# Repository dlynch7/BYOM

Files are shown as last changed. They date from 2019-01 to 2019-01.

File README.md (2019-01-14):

# [B]uild [Y]our [O]wn [M]otor
Build and control a brushless DC (BLDC) motor.

Introductory project for Robot Design Studio (ME 495/EECS 495) 2019 at Northwestern University.

The project name is a bit of a misnomer: you won't build a motor from scratch, however you will be able to select from a number of motor winding options, allowing you to make design decisions about the motor's speed-torque curve.

## Parts list
- [Turnigy TrackStar 21.5T sensored BLDC motor](https://hobbyking.com/en_us/turnigy-trackstar-21-5t-sensored-brushless-motor-1855kv-roar-approved.html)
- [Texas Instruments EK-TM4C123GXL LaunchPad](http://www.ti.com/tool/EK-TM4C123GXL) (evaluation kit for Tiva TM4C123GH6PM microcontroller)
- [Texas Instruments BOOSTXL-DRV8323RS](http://www.ti.com/general/docs/litabsmultiplefilelist.tsp?literatureNumber=slvub01c) (evaluation kit for DRV8323Rx gate driver IC)

## BLDC connector
The BLDC has a 6-pin connector, but because it isn't immediately clear what each pin does, I removed the top half of the can and did some probing with a multimeter.

Inside, the Hall sensors are mounted to a circular PCB that sits above the coils.
The Halls are surface-mount components much like [these ones from TI](http://www.ti.com/product/DRV5055), with GND on one side of the IC and VCC and OUT both on the other side, which probably makes it harder to short across GND and Vcc.

Assuming the Halls inside this motor have the same pinout (and I saw many online with this pinout), I was able to figure out which of the 6 pins are VCC and GND, and in short order I had figured out which of the remaining pins were the outputs for the three Hall sensors.

That still left one mystery pin, which I traced to a small 2-pad surface mount component that I suspect is a temperature sensor.

Thus, looking top-down with phase markings right-side-up, the connector pinout is
`GND HALL_1 HALL_2 HALL_3 TEMP VCC`.

## Pin compatibility check: Tiva and motor driver
The BOOSTXL-DRV8323 motor driver devboard was designed to work TI's MSP430 devboard, and although the BOOSTXL devboard snaps onto the Tiva devboard, I want to make sure the pins are compatibile.

TI's documentation for the BOOSTXL-DRV8323 devboard provides a nice table detailing the pin connections between the BOOSTXL-DRV8323 and the MSP430 devboard and explains each pin's functions.
I am reproducing it below and adding a column for the Tiva devboard pins.

<details><summary> Click to expand pin compatibility table</summary>
<p>

| BOOSTXL-DRV8323 pin | BOOSTXL-DRV8323 function | MSP430 pin, function  | Tiva pin, function |
| --- | --- | --- | --- |
| J3-1 | 3.3 V | 3.3 V | 3.3 V |
| J3-2 | no function | 5 V | 5 V |
| J3-3 | VSENVM | P6.5, ADC - A5 | PB5, AIN 11 |
| J3-4 | GND | GND | GND |
| J3-5 | no function | P3.4, I/O pin | PB0, I/O pin |
| J3-6 | VSENA | P6.0, ADC - 0 | PD0, AIN 7 |
| J3-7 | no function | P3.3, I/O pin | PB1, I/O pin |
| J3-8 | VSENB | P6.1, ADC - 1 | PD1, AIN 6 |
| J3-9 | ENABLE | P1.6, I/O w/ INT | PE4, I/O w/ INT |
| J3-10 | VSENC | P6.2, ADC - 2 | PD2, AIN 5 |
| J3-11 | POT | P6.6, ADC - A6 | PE5, AIN 8 |
| J3-12 | ISENC | P6.3, ADC - 3 | PD3, AIN 4 |
| J3-13 | SCLK | P3.2, SPI CLK | PB4, SSI2 CLK |
| J3-14 | ISENB | P6.4, ADC - 4 | PE1, AIN 2 |
| J3-15 | NFAULT | P2.7, I/O w/ INT | PA5, I/O w/ INT |
| J3-16 | ISENA | P7.0, ADC - 12 | PE2, AIN 1 |
| J3-17 | no function | P4.2, I/O pin | PA6, I/O pin |
| J3-18 | IDRIVE | P3.6, I/O pin | PE3, I/O pin |
| J3-19 | no function | P4.1, I/O pin | PA7, I/O pin |
| J3-20 | VDS | P3.5, I/O pin | PF1, I/O pin |
| J4-1 | INHA | P2.5, TA2.2 | PF2, M1PWM6 |
| J4-2 | GND | GND | GND |
| J4-3 | INLA | P2.4, TA2.1 | PF3, M1PWM7 |
| J4-4 | HALLA | P2.0, SPI ENABLE | PB2, I/O w/ INT |
| J4-5 | INHB | P1.5, TA0.4 | PB3, T3CCP1 |
| J4-6 | HALLB | P2.2, I/O w/ INT | PE0, I/O w/ INT |
| J4-7 | INLB | P1.4, TA0.3 | PC4, M0PWM6 |
| J4-8 | no function | P7.4, I/O pin | PF0, I/O pin |
| J4-9 | INHC | P1.3, TA0.2 | PC5, M0PWM7 |
| J4-10 | no function | RST | RST |
| J4-11 | INLC | P1.2, TA0.1 | PC6 |
| J4-12 | SDI | P3.0, MOSI | PB7, MOSI |
| J4-13 | MODE | P4.3, I/O pin | PC7 |
| J4-14 | SDO | P3.1, MISO | PB6, MISO |
| J4-15 | LED | P4.0, I/O pin | PD6, I/O pin |
| J4-16 | HALLC | P2.6, I/O w/ INT | PA4, I/O w/ INT |
| J4-17 | EVM ID | P3.7, I/O pin | PD7, I/O pin |
| J4-18 | nSCS/GAIN | P2.2, I/O w/ INT | PA3, I/O w/ INT |
| J4-19 | EVM ID | P8.2, I/O pin | PF4, I/O pin |
| J4-20 | CAL | P8.1, I/O pin | PA2, I/O pin |

</p>
</details>

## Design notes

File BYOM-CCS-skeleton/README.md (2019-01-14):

# BYOM-CCS-skeleton
Comments-only template for BYOM project.
Most of the code is stripped out, except for a few basic functions.
You will follow the guidelines in the comments to write your own code.

## Basic guidelines
* `bldc.{c,h}` contains high-level commutation code and should be hardware-agnostic.
* `drv8323rs.{c,h}` contains hardware-specific code and not high-level commutation code.
* `setup.{c,h}` contains functions that initialize other things not essential to BLDC commutation.
* Call all setup functions from the main function inside `main.c`. Don't write out any setup functions inside the main function in `main.c`; define them in the appropriate C file.
* All hardware interrupts need to be registered in the interrupt vector table in `tm4c123gh6pm_startup_ccs.c`. Pay attention to the use of the `extern` keyword in the function prototypes of the Hall sensor interrupt handlers in `drv8323rs.h` (the functions are defined in `bldc.c`).
* If your program hangs during execution and you have debugged your functions, you may need to increase the stack size. CCS has made this hard to find.
    * Right-click on your project in the 'Project Explorer' window, then click on 'Properties', scroll down on the left and expand the options for 'ARM Linker', and then click on 'Basic Options'.
    * This should bring up a dialog with an option to 'Set C system stack size'; enter a larger number in the corresponding field (for example, change 512 to 1024).

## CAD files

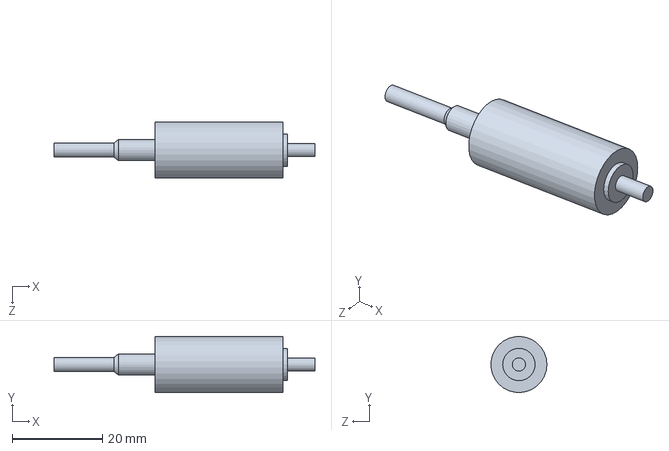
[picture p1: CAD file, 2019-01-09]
CAD/rotor.SLDPRT
58.0 x 12.5 x 12.4 mm

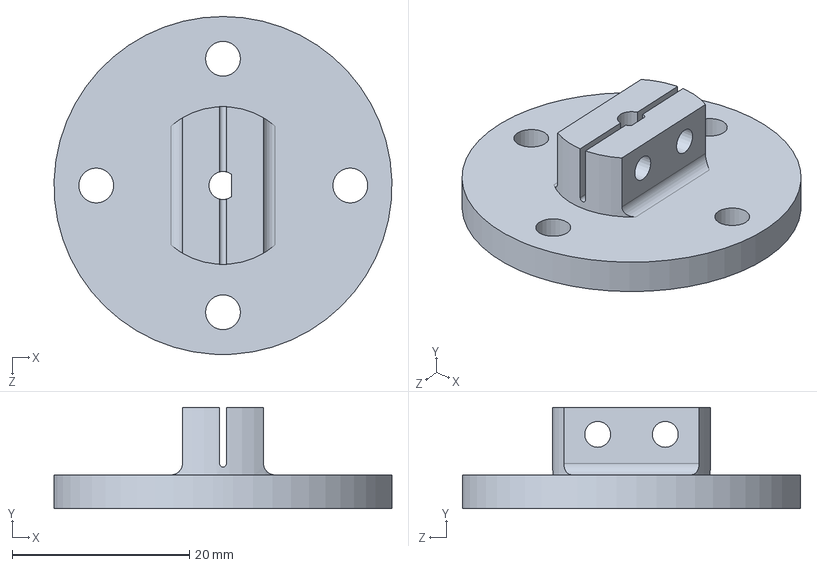
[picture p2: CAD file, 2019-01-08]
CAD/BYOM_hub.SLDPRT
38.1 x 11.4 x 38.1 mm

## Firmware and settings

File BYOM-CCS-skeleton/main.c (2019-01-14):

//*************************************************************************************************
//
// main.c - controls a BLDC motor and provides rudimentary serial logging
//
// Begun: 12/13/18
//
// Copyright (c) 2010-2017 Texas Instruments Incorporated.  All rights reserved.
// Software License Agreement
//
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
//   Redistributions of source code must retain the above copyright
//   notice, this list of conditions and the following disclaimer.
//
//   Redistributions in binary form must reproduce the above copyright
//   notice, this list of conditions and the following disclaimer in the
//   documentation and/or other materials provided with the
//   distribution.
//
//   Neither the name of Texas Instruments Incorporated nor the names of
//   its contributors may be used to endorse or promote products derived
//   from this software without specific prior written permission.
//
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
// This is part of revision 2.1.4.178 of the Tiva Firmware Development Package.
//
//************************************************************************************************/

// include standard C things: (math, stdarg, stdbool, stdint, stdio, string)

// include Tivaware inc/ stuff: (hw_ints, hw_memmap, hw_timer, hw_types, hw_uart)

// include Tivaware driverlib/ stuff: (fpu, gpio, interrupt, pin_map, sysctl, systick, timer, uart)

// include Tivaware utils/uartstdio (for serial console)

// include header files you wrote for this project:

// Macros
#define MOTOR_CONTROL_FREQ // frequency of timer A0 interrupt (in Hz)
#define NUM_SAMPLES // Figure out how many samples you can fit in flash. 3 secs?

// Global variables
volatile uint16_t logData[NUM_SAMPLES]; // Stores the test data
volatile bool doneLogging;
volatile uint16_t logCount; // the number of samples logged

//*************************************************************************************************
//
// This function sets up UART0 to be used for a console to display info as the programs runs.
// It requires Tivaware's uartstdio.{c,h} utility.
//
//************************************************************************************************/
void InitConsole(void)
{
    SysCtlPeripheralEnable(SYSCTL_PERIPH_GPIOA); // Enable GPIO port A which is used for UART0 pins.
    SysCtlPeripheralEnable(SYSCTL_PERIPH_UART0); // Enable UART0 so that we can configure the clock.
    GPIOPinConfigure(GPIO_PA0_U0RX); // pin muxing
    GPIOPinConfigure(GPIO_PA1_U0TX); // pin muxing
    GPIOPinTypeUART(GPIO_PORTA_BASE, GPIO_PIN_0 | GPIO_PIN_1); // Select the alternate (UART) function$
    UARTClockSourceSet(UART0_BASE, UART_CLOCK_PIOSC); // Use the internal 16MHz oscillator as the UART$
    UARTStdioConfig(0, 115200, SysCtlClockGet()); // Initialize the UART for console I/O.
    UARTprintf("\n\nConsole on UART0 is up.\n");
}


//********************************************************************************************
//
// The interrupt handler for the periodic interrupt generated by Timer A0
//
//********************************************************************************************
void MotorControlInterruptHandler(void)
{
    // 1) clear the timer interrupt

    // 2) if the logging array is not full, log another sample
    // and increment the number of samples logged;
    // If array is full, set doneLogging to 1 to notify main loop.
    // What goes into the array?
    // - get_current() returns a uint16_t but the most significant nibble is empty
    // - use the most significant nibble to store the HallState
    // - Implement this combination of current & HallState by adding and bitshifting.

}

//*********************************************************************************************
//
// This function sets up timer A0 to generate interrupts
// at frequency specified by MOTOR_CONTROL_FREQ (#define'd above)
//
//*********************************************************************************************
void TimerBegin(void)
{
    // Enable the timer peripheral.
    // Enable processor interrupts.
    // Configure a 32-bit periodic timer.
    // Set the timer load based on MOTOR_CONTROL_FREQ
    // Setup the interrupts for the timer timeouts.
    // set the Timer 0A interrupt priority to be "low"
    // Enable timer interrupts
    // Enable the timer.
    // register the interrupt handler
    UARTprintf("Timer A0 initialized at %d Hz!\n",MOTOR_CONTROL_FREQ);
}


// Main function:
int main(void) {
    //*****************************************************************************************
    //
    // Local variable declarations
    //
    //*****************************************************************************************
    uint16_t i = 0; // counter used when writing log over serial

    //*****************************************************************************************
    //
    // Startup
    //
    //*****************************************************************************************
    doneLogging = 0;
    logCount = 0;

    // Allow interrupt handlers to use floating-point instructions,
    // at the expense of extra stack usage:
    FPULazyStackingEnable();

    // Set the clocking to run directly from the external crystal/oscillator:
    SysCtlClockSet(SYSCTL_SYSDIV_1 | SYSCTL_USE_OSC | SYSCTL_OSC_MAIN | SYSCTL_XTAL_16MHZ);

    // Set up the serial console to use for displaying messages:
    InitConsole();

    // Call the setup function that initializes an unused pin to visualize ISR timing.


    // Set up the BLDC motor

    // Initialize the timer that will generate interrupts at MOTOR_CONTROL_FREQ

    UARTprintf("Setup complete!\n");

    // Read the Hall state once before entering the main loop
    HallState = read_halls();

    // Commutate once before entering the main loop (kickstart the motor)
    bldc_commutate(-10,HallState);

    //*****************************************************************************************
    //
    // Superloop:
    //
    //*****************************************************************************************
	while(1)
	{
        // don't do anything until done logging motor data
	    if(doneLogging) {
            // Do a safe shutdown
            // 1 - stop commutating by first disabling Hall interrupts
	        // disable Hall A interrupts
	        // disable Hall B interrupts
	        // disable Hall C interrupts

            // 2 - disable each motor phase (INLx)
            // disable phase A
            // disable phase B
            // disable phase C

	        UARTprintf("Hall state, Current(counts)\n");
	        for(i=0; i<NUM_SAMPLES; i++) {
                UARTprintf("\t%d,%d\n", (logData[i] & 0xF000) >> 12, logData[i] & 0x0FFF);
	        }
	        break;
	    }
	}
    return 0; // something, somewhere, went horribly wrong.
}

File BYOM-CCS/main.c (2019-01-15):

// A simple brushless motor driver.

#include <math.h>
#include <stdarg.h>
#include <stdbool.h>
#include <stdint.h>
#include <stdio.h>
#include <string.h>

#include "inc/hw_ints.h"
#include "inc/hw_memmap.h"
#include "inc/hw_timer.h"
#include "inc/hw_types.h"
#include "inc/hw_uart.h"

#include "driverlib/fpu.h"
#include "driverlib/gpio.h"
#include "driverlib/interrupt.h"
#include "driverlib/pin_map.h"
#include "driverlib/sysctl.h"
#include "driverlib/systick.h"
#include "driverlib/timer.h"
#include "driverlib/uart.h"

#include "utils/uartstdio.h"

#include "bldc.h"
#include "drv8323rs.h"

// Frequency of timer A0 interrupt (in Hz)
#define LOG_FREQ 5000

// Number of samples to record
#define NUM_SAMPLES 15000

 // Global test data array
volatile uint16_t logData[NUM_SAMPLES];

// Global flag set when logging completes
volatile bool doneLogging = 0;

// Global counter of the number of samples logged
volatile uint16_t logCount = 0;


// Sets up UART0 to be used for a console to display info as the programs runs.
void InitConsole(void) {
    // Enable GPIO port A which is used for UART0 pins, and enable UART0
    SysCtlPeripheralEnable(SYSCTL_PERIPH_GPIOA);
    SysCtlPeripheralEnable(SYSCTL_PERIPH_UART0);

    // Pin configuration
    GPIOPinConfigure(GPIO_PA0_U0RX);
    GPIOPinConfigure(GPIO_PA1_U0TX);

    // Select the alternate (UART) function
    GPIOPinTypeUART(GPIO_PORTA_BASE, GPIO_PIN_0 | GPIO_PIN_1);

    // Use the internal 16MHz oscillator as the UART
    UARTClockSourceSet(UART0_BASE, UART_CLOCK_PIOSC);

    // Initialize the UART for console I/O
    UARTStdioConfig(0, 115200, SysCtlClockGet());

    // Print debug information
    UARTprintf("\n\nConsole on UART0 is up.\n");
}


// The interrupt handler for the periodic interrupt generated by Timer A0
void LogInterruptHandler(void) {
    // Clear the timer interrupt
    TimerIntClear(TIMER0_BASE, TIMER_TIMA_TIMEOUT);

    // Toggle pin B0, to permit validation of log frequency on oscilloscope
    if (GPIOPinRead(GPIO_PORTB_BASE, GPIO_PIN_0))
        GPIOPinWrite(GPIO_PORTB_BASE, GPIO_PIN_0, 0);
    else
        GPIOPinWrite(GPIO_PORTB_BASE, GPIO_PIN_0, GPIO_PIN_0);

    // Log until the array is full
    if(logCount < NUM_SAMPLES) {
        // Log the current and the hall state as a single 16-bit quantity
        logData[logCount] = GetCurrent() + (HallState << 12);

        logCount++;
    }
    else
        doneLogging = 1;
}


// This function sets up timer A0 to generate interrupts at frequency specified by LOG_FREQ
void LogTimerSetup(void) {
    // Enable Timer 0
    SysCtlPeripheralEnable(SYSCTL_PERIPH_TIMER0);

    // Enable processor interrupts
    IntMasterEnable();

    // Configure the timer as a 32-bit periodic timer
    TimerConfigure(TIMER0_BASE, TIMER_CFG_PERIODIC);

    // Set the timer load value
    TimerLoadSet(TIMER0_BASE, TIMER_A, SysCtlClockGet() / LOG_FREQ);

    // Enable timer A0 interrupts, set the timer A0 interrupt priority to be "low"
    IntEnable(INT_TIMER0A);
    IntPrioritySet(INT_TIMER0A, 0x20);

    // Enable the specific interrupt we want (timeout interrupt), and register the interrupt service routine
    TimerIntEnable(TIMER0_BASE, TIMER_TIMA_TIMEOUT);
    TimerIntRegister(TIMER0_BASE, TIMER_A,LogInterruptHandler);

    // Enable GPIO port B
    SysCtlPeripheralEnable(SYSCTL_PERIPH_GPIOB);
    while(!SysCtlPeripheralReady(SYSCTL_PERIPH_GPIOB));

    // Set pin B0 as an output, and initialize it to LOW
    GPIOPinTypeGPIOOutput(GPIO_PORTB_BASE, GPIO_PIN_0);
    GPIOPinWrite(GPIO_PORTB_BASE, GPIO_PIN_0, 0);

    // Enable the timer
    TimerEnable(TIMER0_BASE, TIMER_A);
}


// Main function:
int main(void) {

    FPULazyStackingEnable(); // Allow interrupt handlers to use floating-point instructions at the expense of extra stack usage

    // Set the clocking to run directly from the external crystal/oscillator:
    SysCtlClockSet(SYSCTL_SYSDIV_1 | SYSCTL_USE_OSC | SYSCTL_OSC_MAIN | SYSCTL_XTAL_16MHZ);

    // Set up the serial console
    InitConsole();
    UARTprintf("Console initialized.\n");

    // Set up brushless motor control
    UARTprintf("Setting up motor drive...\n");
    MotorSetup();

    // Start the log interrupt
    UARTprintf("Setting up log timer...\n");
    LogTimerSetup();

    // Read the hall state and commutate once to force the motor to start turning
    MotorCommutate(DUTY_CYCLE);

	while(1)
	{
	    if(doneLogging) {
	        int i;

	        UARTprintf("Hall state, Current(counts)\n");
	        for(i=0; i<NUM_SAMPLES; i++) {
                UARTprintf("\t%d,%d\n", (logData[i] & 0xF000) >> 12, logData[i] & 0x0FFF);
	        }
	        break;
	    }
	}

    return 0;
}

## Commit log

2018-12-12 added blurb on connector reverse-engineering
2018-12-12 added links to MCU and gate driver devboards to README
2018-12-12 added motor driver devboard user's guide
2018-12-12 began pin compatibility table
2018-12-13 added Tiva pin functions to pin compatibility table
2018-12-13 added note to Tiva entry for pin J4-11
2018-12-13 made pin compatibility table collapsable
2018-12-13 skeleton of no-OS motor control Tiva app
2018-12-13 added datasheet for DRV8323 gate driver IC
2018-12-13 skeleton of FreeRTOS-based motor control Tiva app
2018-12-13 clarified README for FreeRTOS-based Tiva motor control app
2018-12-14 added pin names to Tiva column of pin compatibility table in top-level README
2018-12-14 pin compatibility table correction: added interrupt support to Tiva pin PB2 in top-level README
2018-12-14 fixed typo in Tiva pin PC5 in pin compatibility table in top-level README
2018-12-15 beginning a library to interface with BOOSTXL-DRV8323RS motor driver - added PWM init functions
2018-12-15 more components of skeleton of motor control app
2018-12-15 fixed drift between timer3B pwm and other pwm modules (forgot to -1 in the 'load' register)
    [drv8323rs.c]
2018-12-15 made individual pwm init functions static and added extern init_all_pwms() function
2018-12-15 added SPI initialization functions for communication with DRV8323RS
2018-12-16 added wrapper SPI I/O functions to interface with DRV8323RS
2018-12-16 developing high-level BLDC library for setup and commutation - based on NU Mechatronics PIC32 examples
2018-12-16 barebones main(), right now only calls bldc_setup() and inits a timer-based interrupt at 1 kHz
2018-12-16 changed pin names: 'ADC x' to 'AIN x'
2018-12-16 added ADC setup and read functions for DRV8323RS current sense
2018-12-16 added simple function to print raw ISENSE ADV values
2018-12-16 still developing BLDC and DRV8323RS setup functions, code not set up to commutate yet
2018-12-17 added interface for Hall sensors
2018-12-18 added abstraction layer so commutation code doesn't need to know which PWM modules are real PWM modules and which are implemented with timers
    [bldc.c]
2018-12-18 added temporary features to Hall sensor input capture ISRs for development
2018-12-18 added a GPIO pin PB0 to toggle for measuring timing accuracy on scope
2018-12-18 useful mid/high-level guide to BLDC commutation/control
2018-12-18 moved Hall sensor input capture interrupt handlers to bldc.{c,h} and added some temporary serial prints to them for development
2018-12-18 corrected INLA GPIO port definition
    [drv8323rs.h]
2018-12-18 cannot do 0% duty cycle on PWMs, so I'm saturating at 1% instead.
2018-12-18 adjusting startup sequence, debugging SPI comms with UARTprintf() statements
2019-01-02 Copied Dan's prototype motor code over to CCS
2019-01-02 Got commutation working without load, but found applying load caused driver output voltage to dip quickly on each PWM pulse.
2019-01-03 Got motor spinning
2019-01-03 Removed extraneous code, cleaned up main in preparation to write fixed-duration test.
    [bldc.c, main.c, setup.c]
2019-01-03 Reverted state to commit before 'cleanup'
    [bldc.c, main.c, setup.c]
2019-01-03 Added auto-start back in after revert
    [bldc.c, main.c]
2019-01-04 Got current measurement and reporting working as a one-shot test
2019-01-08 Added CAD for flywheel hub 3D print concept
    [BYOM_hub.SLDPRT]
2019-01-08 Added rotor CAD and documentation for 8323 dev board schematic
    [rotor.SLDPRT]
2019-01-09 simple script for fitting a curve to quantized motor speed data
2019-01-14 stripped out most of the DRV8323RS-specific code except for a few low-level functions that take a while to get right and aren't crucial to understanding BLDC commutation
2019-01-14 stripped out commutation table code and some other stuff from bldc.c
2019-01-14 smoothing speed estimates with zero-phase digital filter in MATLAB
2019-01-15 parsing hall states and current counts from putty log, filtering and differencing
2019-01-15 Added constants for ADC setup
2019-01-15 Added constants for PWM device setup
